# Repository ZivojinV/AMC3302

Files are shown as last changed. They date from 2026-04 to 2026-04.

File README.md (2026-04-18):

# AMC3302-Based Precision Full-Wave Rectifier PCB

## Description
Custom AMC3302-based full-wave rectifier PCB for AC signal measurement and conditioning.

## Overview
The input AC signal is measured using the AMC3302 isolated amplifier and further processed through a dual MCP6022 stage to produce a full-wave rectified output.

The system was iteratively tested and validated through signal measurement and analysis to ensure correct behavior and stable output.

## Hardware
- Custom PCB design  
- AMC3302 isolated amplifier  
- Dual MCP6022 operational amplifiers  
- LM78L05 voltage regulator  

**Images:**

- Empty PCB  
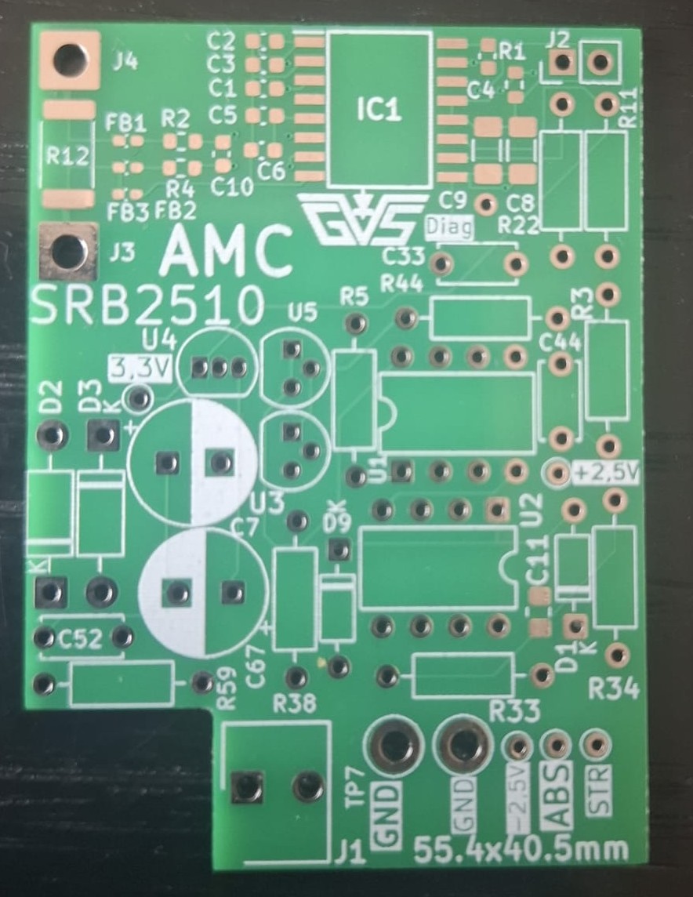
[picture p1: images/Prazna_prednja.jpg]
Empty PCB - Front side

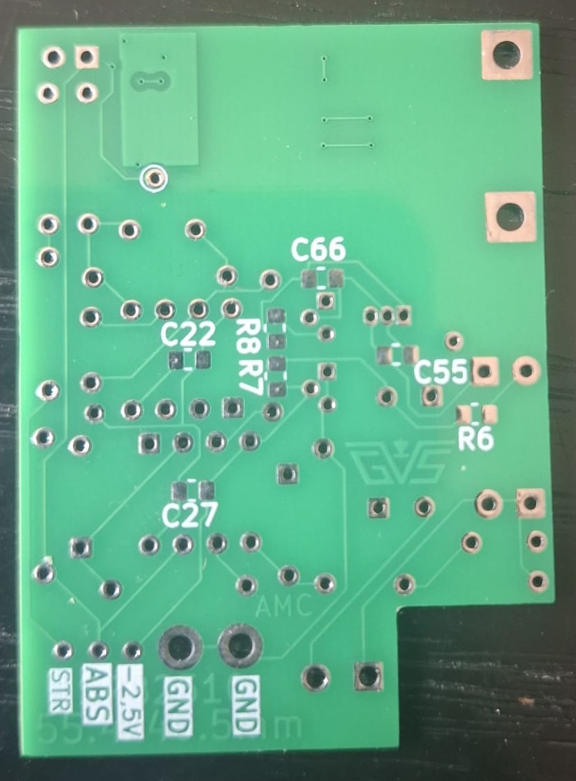
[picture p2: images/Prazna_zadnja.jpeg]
Empty PCB - Bottom side


- Assembled PCB  
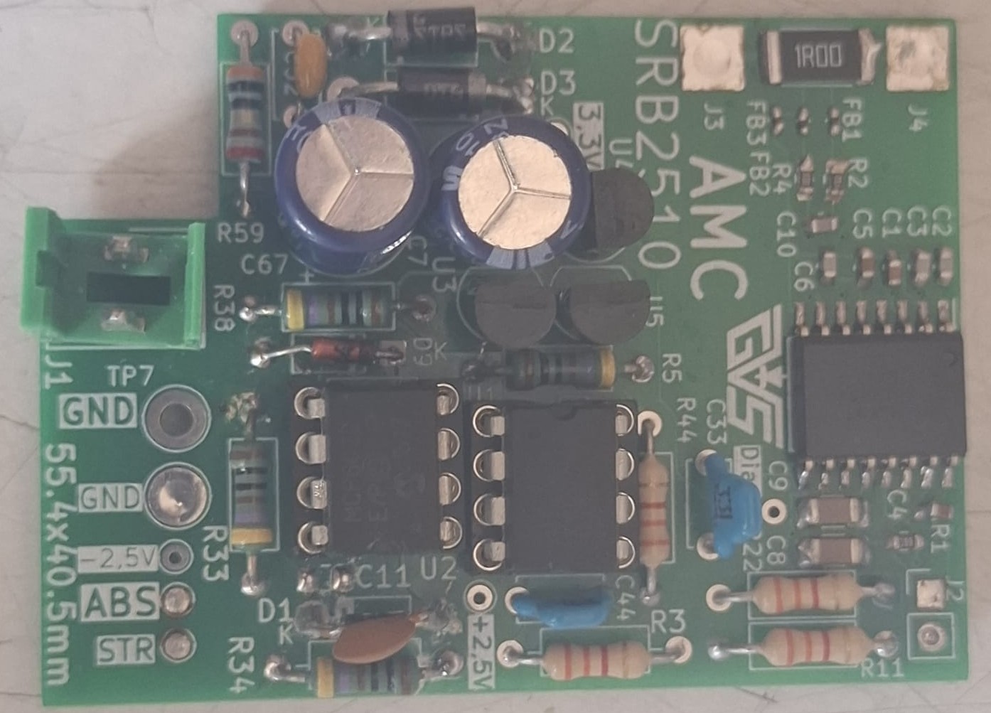
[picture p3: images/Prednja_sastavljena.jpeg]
Assembled PCB - Front side

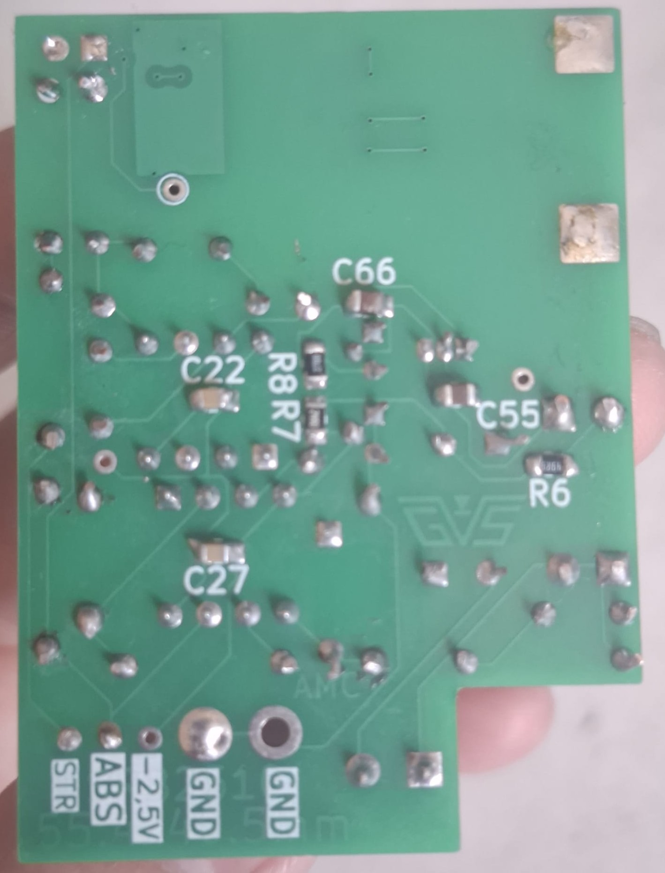
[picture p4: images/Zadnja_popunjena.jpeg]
Assembled PCB - Bottom side


## Results
Signal verification through measurement:

- Input signal  
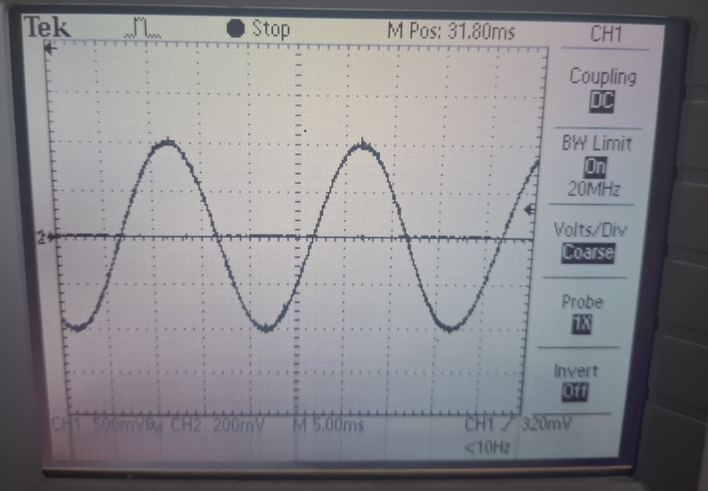
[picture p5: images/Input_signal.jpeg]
Input signal


- Rectified output signal  
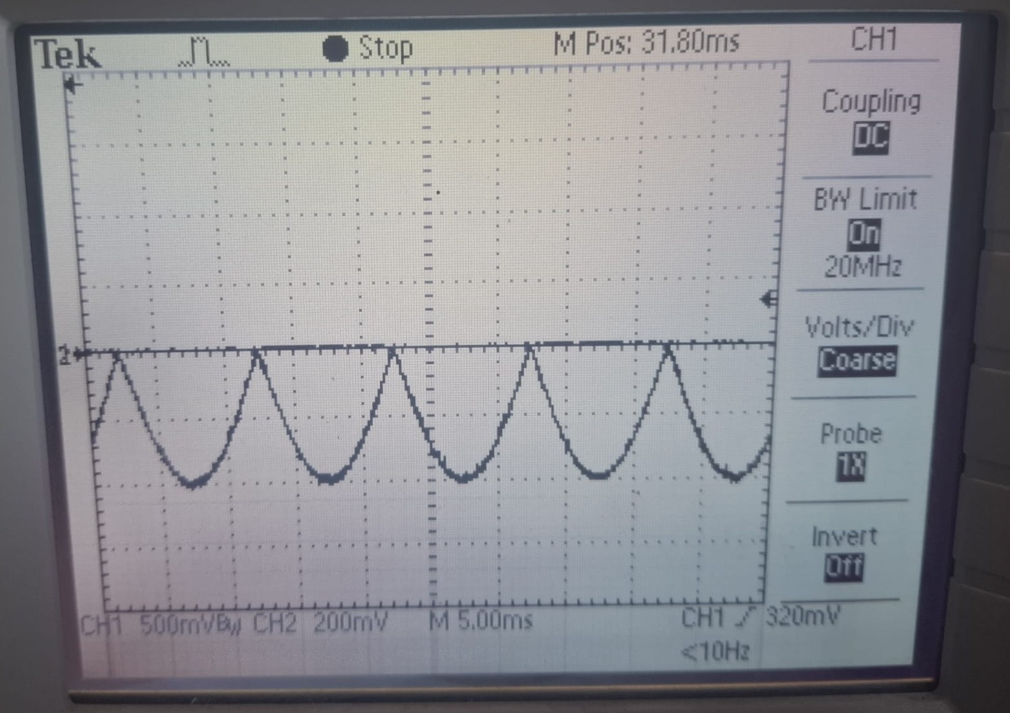
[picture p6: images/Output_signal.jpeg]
Output signal


- Input vs Output comparison  
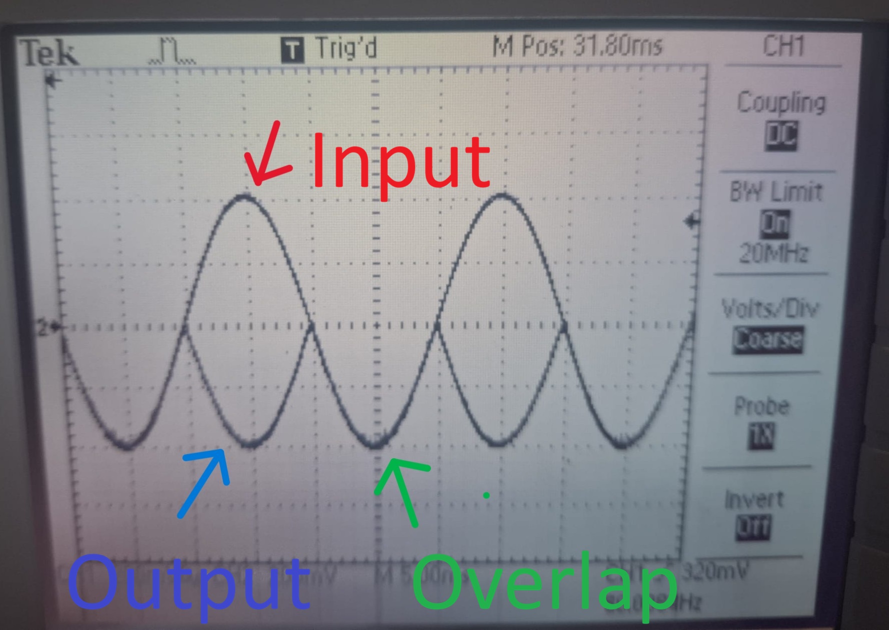
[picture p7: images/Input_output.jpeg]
Input vs output comparison


## Status
- Designed and assembled  
- Tested and validated through measurement  
- Functionality confirmed  

## Notes
Additional capacitors were introduced after testing to reduce noise and improve output signal stability.

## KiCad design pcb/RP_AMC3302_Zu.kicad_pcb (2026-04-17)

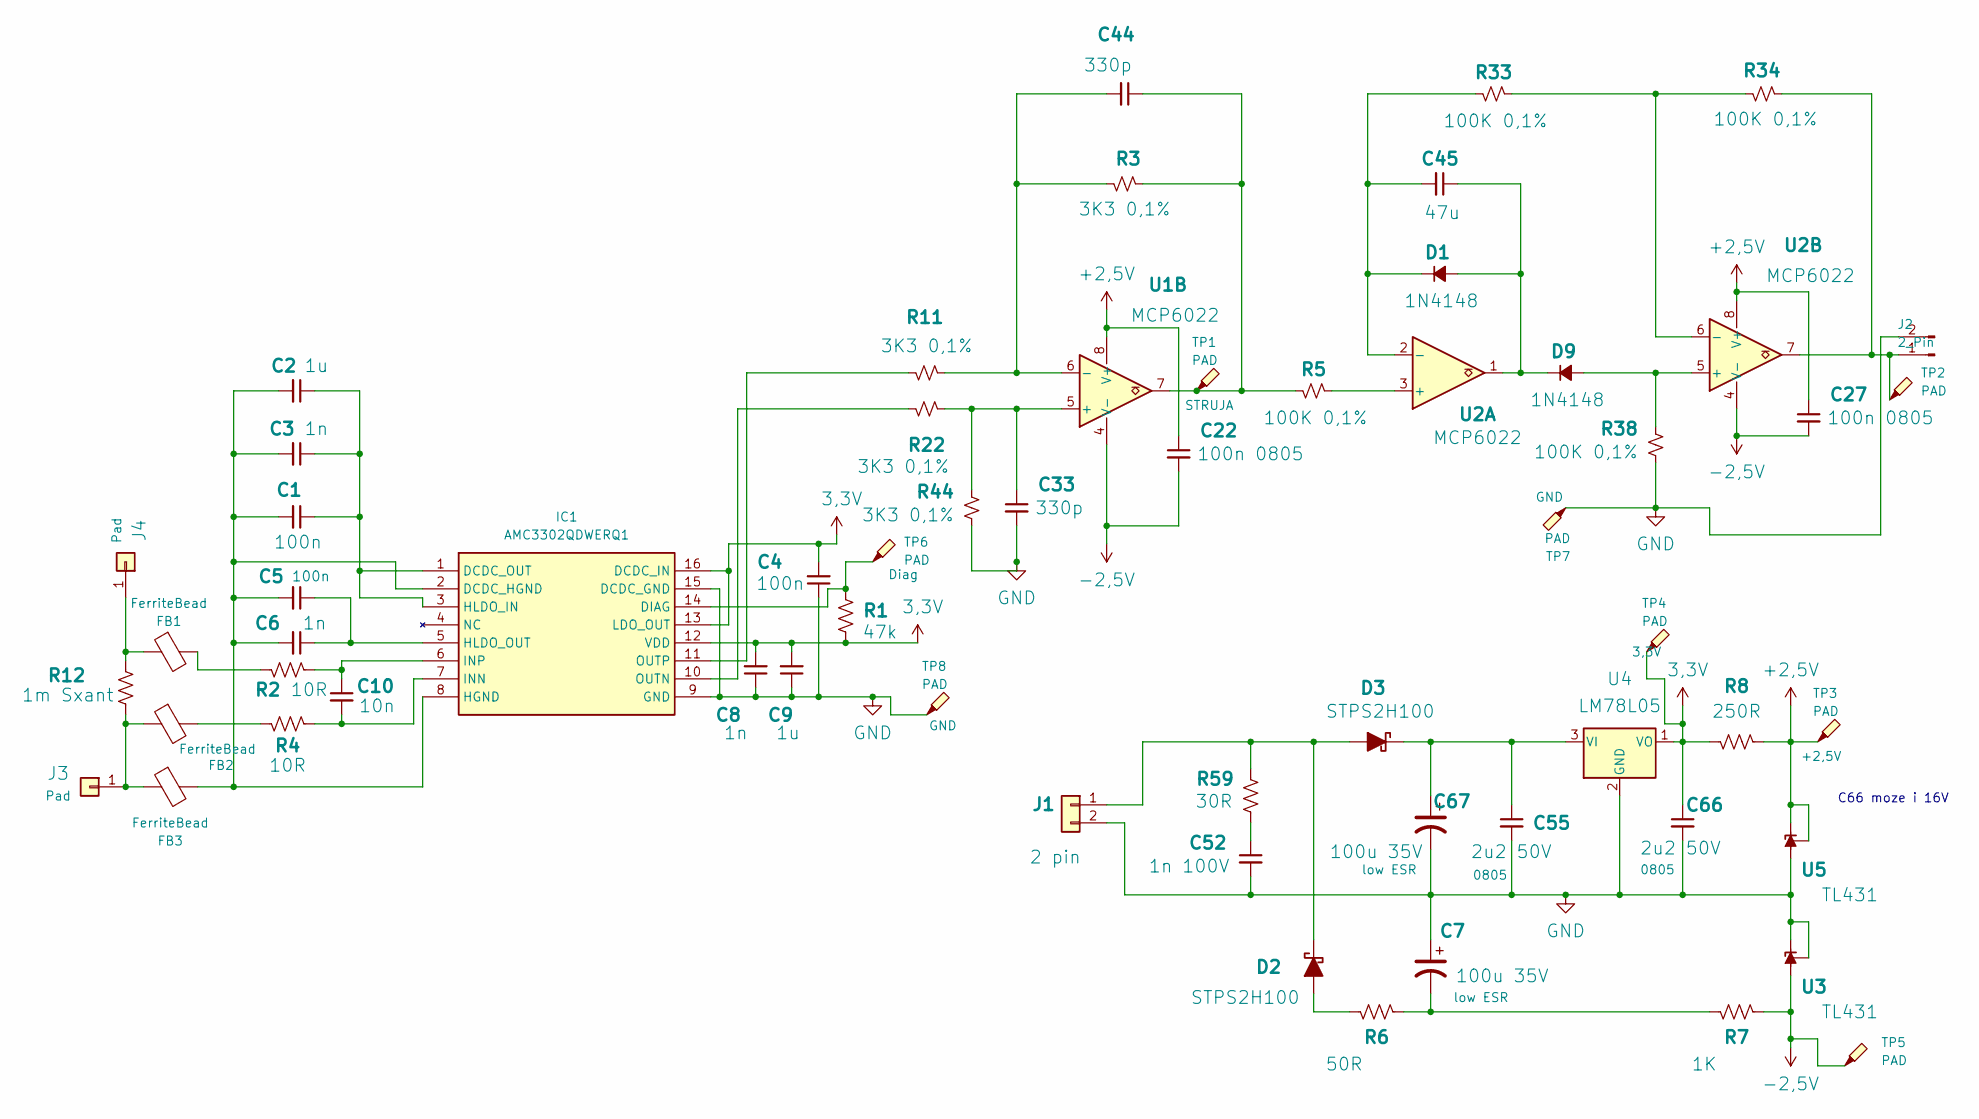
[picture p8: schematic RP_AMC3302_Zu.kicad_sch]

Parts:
C1, C4, C5: 100n; C_0603_1608Metric_Pad1.08x0.95mm_HandSolder
C2: 1u; C_0603_1608Metric_Pad1.08x0.95mm_HandSolder
C3, C6: 1n; C_0603_1608Metric_Pad1.08x0.95mm_HandSolder
C7, C67: 100u 35V; CP_Radial_D8.0mm_P3.50mm
C8: 1n; C_1206_3216Metric_Pad1.33x1.80mm_HandSolder
C9: 1u; C_1206_3216Metric_Pad1.33x1.80mm_HandSolder
C10: 10n; C_0603_1608Metric
C22, C27: 100n 0805; C_0805_2012Metric_Pad1.18x1.45mm_HandSolder
C33, C44: 330p; C_Disc_D5.0mm_W2.5mm_P5.00mm
C45: 47u; C_Disc_D5.0mm_W2.5mm_P5.00mm
C52: 1n 100V; C_Disc_D5.0mm_W2.5mm_P5.00mm
C55, C66: 2u2 50V; C_0805_2012Metric_Pad1.18x1.45mm_HandSolder
D1, D9: 1N4148; D_DO-35_SOD27_P7.62mm_Horizontal
D2, D3: STPS2H100; D_DO-41_SOD81_P10.16mm_Horizontal
FB1, FB2, FB3: FerriteBead; L_0402_1005Metric_Pad0.77x0.64mm_HandSolder
IC1: AMC3302QDWERQ1; SOIC127P1030X265-16N; Manufacturer_Part_Number AMC3302QDWERQ1; Mouser Part Number 595-AMC3302QDWERQ1
J1: 2 pin; SHDR2W125P0X396_1X2_620X890X1700P
J2: 2_Pin; PinHeader_1x02_P2.54mm_Vertical
J3, J4: Pad; SolderWire-1.5sqmm_1x01_D1.7mm_OD3.9mm
R1: 47k; R_0603_1608Metric
R2, R4: 10R; R_0603_1608Metric
R3, R11, R22, R44: 3K3 0,1%; R_Axial_DIN0207_L6.3mm_D2.5mm_P10.16mm_Horizontal
R5, R33, R34, R38: 100K 0,1%; R_Axial_DIN0207_L6.3mm_D2.5mm_P10.16mm_Horizontal
R6: 50R; R_0805_2012Metric_Pad1.20x1.40mm_HandSolder
R7: 1K; R_0805_2012Metric_Pad1.20x1.40mm_HandSolder
R8: 250R; R_0805_2012Metric_Pad1.20x1.40mm_HandSolder
R12: 1m Sxant; R_2512_6332Metric
R59: 30R; R_Axial_DIN0207_L6.3mm_D2.5mm_P10.16mm_Horizontal
TP1, TP2, TP3, TP4, TP5, TP6: PAD; TestPoint_THTPad_D1.5mm_Drill0.7mm
TP7, TP8: PAD; TestPoint_Loop_D2.50mm_Drill1.85mm
U1, U2: MCP6022; DIP-8_W7.62mm
U3, U5: TL431; TO-92
U4: LM78L05; TO-92_Inline

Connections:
3,3V: C4.2, C8.2, C9.2, C66.1, IC1.12 (VDD), IC1.13 (LDO_OUT), IC1.16 (DCDC_IN), R1.2, R8.2, TP4.1, U4.1 (VO)
+2,5V: C22.1, C27.1, R8.1, TP3.1, U1.8 (V+), U2.8 (V+), U5.1 (REF), U5.3 (K)
-2,5V: C22.2, C27.2, R7.1, TP5.1, U1.4 (V-), U2.4 (V-), U3.2 (A)
GND: C4.1, C7.1, C8.1, C9.1, C33.2, C52.2, C55.2, C66.2, C67.2, IC1.9 (GND), IC1.15 (DCDC_GND), J1.2, J2.2, R38.1, R44.1, TP7.1, TP8.1, U3.1 (REF), U3.3 (K), U4.2 (GND), U5.2 (A)
unnamed: C7.2, R6.1, R7.2
unnamed: C44.1, R3.1, R5.2, TP1.1, U1.7
unnamed: C52.1, R59.2
unnamed 7: C45.1, D1.2 (A), D9.1 (K), U2.1; also elsewhere on the board
unnamed: C45.2, D1.1 (K), R33.2, U2.2 (-)
unnamed: D2.2 (A), R6.2
unnamed: D2.1 (K), D3.2 (A), J1.1, R59.1
unnamed: C55.1, C67.1, D3.1 (K), U4.3 (VI)
unnamed: D9.2 (A), R38.2, U2.5 (+)
unnamed: FB1.2, R2.2
unnamed: FB2.2, R4.2
unnamed: C1.2, C2.2, C3.2, C5.2, C6.2, FB3.2, IC1.2 (DCDC_HGND), IC1.8 (HGND)
unnamed: C1.1, C2.1, C3.1, IC1.1 (DCDC_OUT), IC1.3 (HLDO_IN)
unnamed: IC1.14 (DIAG), R1.1, TP6.1
unnamed: C5.1, C6.1, IC1.5 (HLDO_OUT)
unnamed: C10.2, IC1.7 (INN), R4.1
unnamed: C10.1, IC1.6 (INP), R2.1
unnamed: IC1.10 (OUTN), R22.2
unnamed: IC1.11 (OUTP), R11.2
unnamed: J2.1, R34.1, TP2.1, U2.7
unnamed: FB2.1, FB3.1, J3.1, R12.2
unnamed: FB1.1, J4.1, R12.1
unnamed: C33.1, R22.1, R44.2, U1.5 (+)
unnamed: C44.2, R3.2, R11.1, U1.6 (-)
unnamed: R5.1, U2.3 (+)
unnamed 29: R33.1, R34.2, U2.6 (-); also elsewhere on the board

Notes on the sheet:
C66 moze i 16V

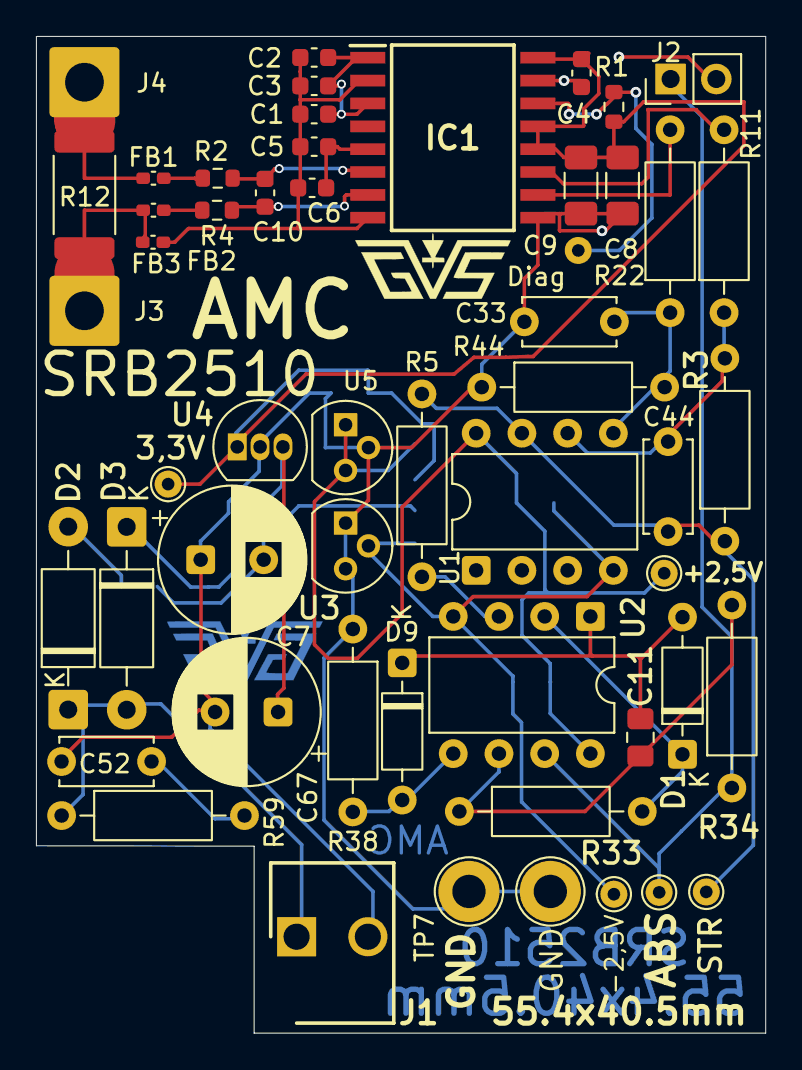
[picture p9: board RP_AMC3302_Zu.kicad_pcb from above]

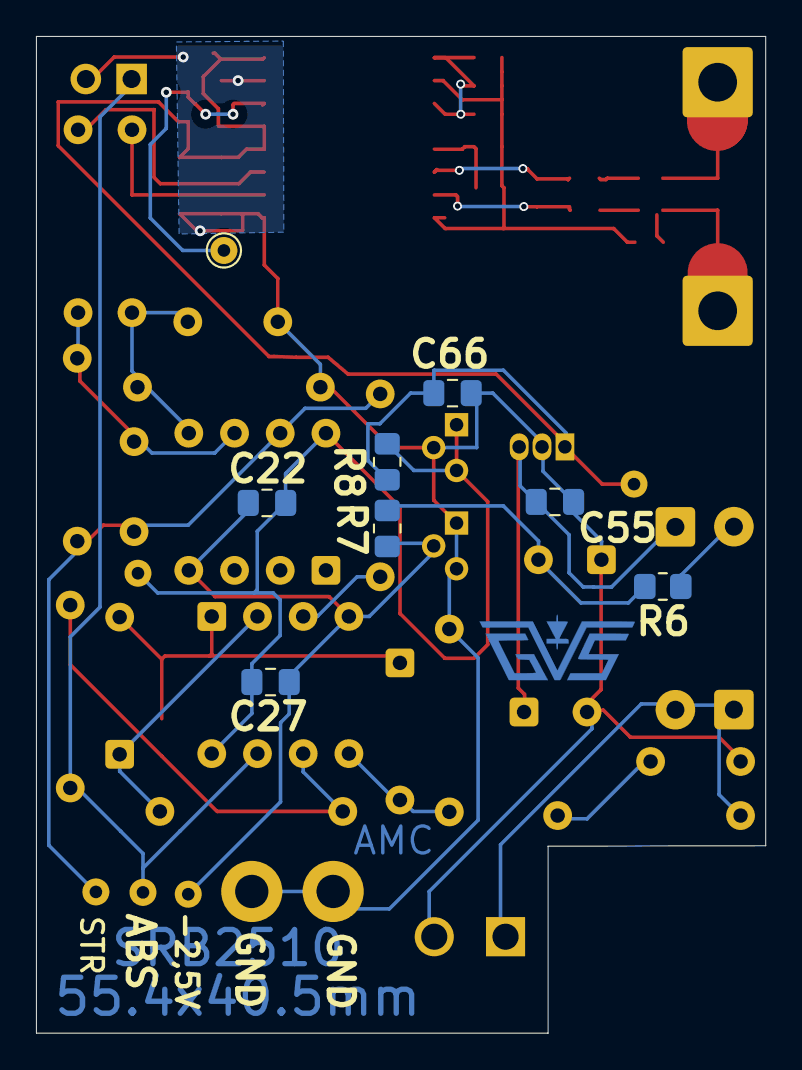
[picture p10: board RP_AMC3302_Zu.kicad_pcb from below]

Board: 2 copper layers, 40.5 x 55.4 mm, 62 parts (9 on the bottom side), 30 nets.

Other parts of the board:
C11: 10p 0805; C_0805_2012Metric_Pad1.18x1.45mm_HandSolder
H1: GVS logo; gvslogo_mali_Cu
H2: GVS logo; gvslogo_mali

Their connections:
unnamed 7: C11.2; also elsewhere on the board
unnamed 29: C11.1; also elsewhere on the board
